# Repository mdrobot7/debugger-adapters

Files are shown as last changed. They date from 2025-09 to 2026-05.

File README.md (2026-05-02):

# debugger-adapters
Aliexpress STLINKv2 debugger to standard connector adapters

## Hardware
All part links are built into the KiCad parts, just generate the BOM from within KiCad and order. Miscellaneous parts are below.

- [Aliexpress STLINKv2](https://www.aliexpress.us/item/3256803389306042.html)
- [Cortex-debug Ribbon Cable](https://www.digikey.com/en/products/detail/cnc-tech/300-30-10-GR-0100F/5864892)
- [Pre-assembled Cortex-debug Cable](https://www.aliexpress.us/item/3256805917162371.html)

## Assembly
The ribbon cable IDC connectors for the Cortex-Debug adapter are quite difficult to get exactly right. If the wire goes in at slightly the wrong angle, the conductors will bridge or connect to the wrong pins. After each connector is put on, check each pin with a multimeter to make sure it's not bridged to anything it shouldn't be.

## Creating a Black Magic Probe
Black Magic Probe and Black Magic Debug are open-source SWD/JTAG debug projects for ARM Cortex microcontrollers. It gives you a bare GDB server and is platform-independent, so it will work on ARM Cortex microcontrollers regardless of brand or series.

To create a Black Magic Probe you need an existing debugger -- another Black Magic Probe, STLink (for ST-based debuggers), Atmel ICE (for Atmel chips), etc.

#### Resources
- [Black Magic Debug Website](https://black-magic.org/index.html)
- [Black Magic Debug Codeberg](https://codeberg.org/blackmagic-debug/blackmagic)
- [dfu-util Homepage](https://dfu-util.sourceforge.net/)
- [Zadig (Windows USB driver reinstaller)](https://zadig.akeo.ie/)

### Supported Hardware
- [Knockoff STLink v2 (Geehy MCU) - Aliexpress](https://www.aliexpress.us/item/3256803389306042.html)
- [Knockoff STLink v2 (STM32F101 MCU) - Aliexpress](https://www.aliexpress.us/item/3256803289344865.html)
- [STM32 "Blue Pill" (STM32F103C8T6) - Ebay](https://www.ebay.com/itm/292145343898)

### Wiring
Keep the SWD wires (between the BMP and the microcontroller) relatively short. SWD doesn't have a length spec, but under 30cm is a good rule of thumb. Slower baud rates will allow for longer lengths. It's recommended to extend the USB side instead of the SWD side.

### Reprogramming the BMP
The Black Magic Probe project switched to Meson in current releases, which makes installation a little harder on Windows. On Windows, your best move is load up a Linux VM using VirtualBox or something similar. You can try to get MSYS2 to work, but no guarantees. Builds and uploads on Windows may need [Zadig](https://zadig.akeo.ie/) to manually assign Windows drivers to your BMP, you want to assign it to **WinUSB**.

Instructions for Linux/Mac:

1. Install dependencies
   - Linux: `sudo apt install meson ninja gcc-arm-none-eabi gdb-multiarch binutils-arm-none-eabi dfu-util libhidapi-dev libftdi1-dev libusb-1.0-0-dev`
   - OSX: `brew install meson ninja arm-none-eabi-gcc arm-none-eabi-binutils arm-none-eabi-gdb dfu-util hidapi libftdi libusb`
3. `git clone https://codeberg.org/blackmagic-debug/blackmagic`
4. `cd` into the directory you cloned into
5. Set up the build: `meson setup build --reconfigure --cross-file cross-file/stlink.ini -Dtargets=cortexar,cortexm,sam,stm,nxp,ti -Dbmd_bootloader=true`
   - Which targets you choose are up to you and your use case. The ones shown above are a general recommendation. See [supported targets](https://black-magic.org/supported-targets.html) for others.
6. Build the binary and bootloader: `meson compile -C build; meson compile -C boot-bin`
7. Pull the metal shell off of your BMP-to-be by pulling it towards the USB port. Attach jumper wires to an existing BMP, and wire GND, VCC, SWDIO, and SWCLK to the pins/exposed pads on your BMP-to-be. You can wire it properly, or hold wires onto the pads until the next command is done.
8. Flash the bootloader
   - With an existing BMP: `arm-none-eabi-gdb -ex "tar ext [debugger device ID]" -ex "mon s" -ex "att 1" -ex "mon option erase" -ex "load" -batch build/blackmagic_stlink_bootloader.elf`
     - Find the debugger device ID in /dev. Use /dev/whatever for the following commands.
     - This worked on some targets (Geehy micros), but not all. I've received knockoff STLinks from AliExpress that have flash protections set up such that it doesn't flash. If so, grab a stock STLink and try the steps below.
   - With an existing STLink (credit to [this guide](https://microcontrollerelectronics.com/how-to-convert-an-stm32f103c8t6-into-a-black-magic-probe/)):
     - `sudo apt install openocd stlink-tools`
     - `sudo vim /usr/share/openocd/scripts/target/stm32f1x.cfg` and add `set CPUTAPID 0` below line 35. This disables CPU ID checking (we're flashing a counterfeit).
     - Plug in your existing STLinkv2 and connect it to your BMP-to-be.
     - `openocd -f interface/stlink-v2.cfg -f target/stm32f1x.cfg -c "init" -c "halt" -c "stm32f1x unlock 0" -c "shutdown" && st-flash erase && st-flash --flash=0x20000 --reset write build/blackmagic_stlink_bootloader.bin 0x8000000`
9. Plug your new BMP into your PC via USB, **unplug your existing debugger**.
10. Check that your new BMP shows up: `sudo dfu-util -l`. It should say "found DFU" with some device information.
11. Flash the BMP firmware: `sudo dfu-util -s 0x08002000:leave:force -D build/blackmagic_stlink_firmware.bin`

### Upgrading Your BMP
All you need to do is `git pull` the updated BMP firmware (or make any changes you need to), and rebuild. Plug it in via USB and rerun step 11 above. The bootloader handles reflashing the firmware over USB.

Black Magic Probe releases official binaries as well, so you can also download the `blackmagic-native` BIN file from the [Releases](https://codeberg.org/blackmagic-debug/blackmagic/releases) page and flash it over DFU. It covers a very similar set of debug targets and fits in the 128KB flash of our counterfeit STLinks.

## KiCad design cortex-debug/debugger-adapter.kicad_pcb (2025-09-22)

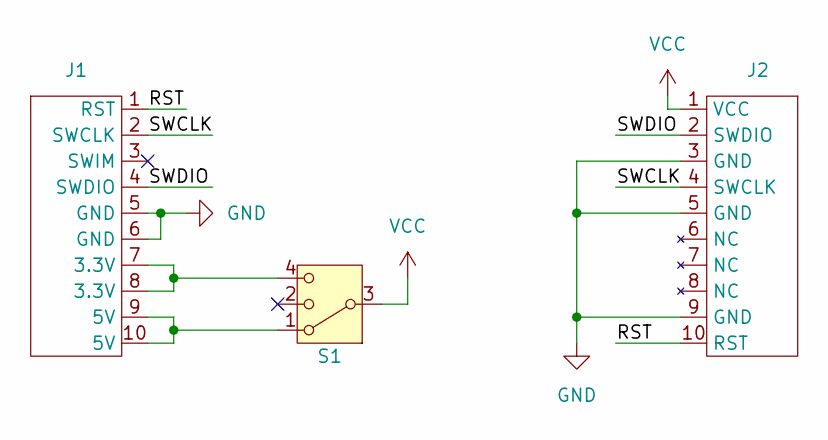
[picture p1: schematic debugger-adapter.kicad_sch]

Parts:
J1: STLINK_Header; Manufacturer Part Number SFH11-PBPC-D05-ST-BK; Digikey Part Number S9194-ND
J2: 0.05in_Ribbon_Header; Manufacturer Part Number 3240-10-00; Digikey Part Number 1175-1664-ND
S1: Slide_SP3T; Manufacturer Part Number CL-SB-13A-01T; Digikey Part Number 563-1326-1-ND

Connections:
/RST: J1.1 (RST), J2.10 (RST)
/SWCLK: J1.2 (SWCLK), J2.4 (SWCLK)
/SWDIO: J1.4 (SWDIO), J2.2 (SWDIO)
GND: J1.5 (GND), J1.6 (GND), J2.3 (GND), J2.5 (GND), J2.9 (GND)
unnamed: J1.7 (3.3V), J1.8 (3.3V), S1.4
unnamed: J1.9 (5V), J1.10 (5V), S1.1
VCC: J2.1 (VCC), S1.3

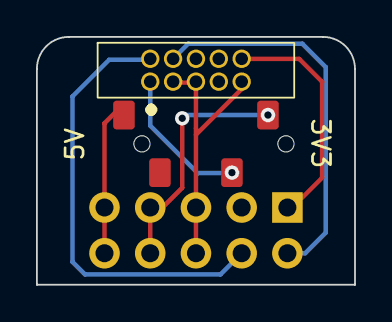
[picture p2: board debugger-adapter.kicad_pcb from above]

Board: 2 copper layers, 17.7 x 13.8 mm, 3 parts (1 on the bottom side), 7 nets.

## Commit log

2024-02-16 Created cortex debug/swd debugger adapter
    I already made this in altium, this is the kicad version of it. Made all of the parts in their own common library so that making different adapters is easy in the future for stuff like JTAG, ST, AVR,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
    [debugger-adapter.kicad_pcb, debugger-adapter.kicad_sch]
2024-02-19 Added part links
    [debugger-adapter.kicad_sch]
2024-11-24 Add aliexpress pre-assembled cable to readme, export project files
    [debugger-adapter.kicad_pcb, debugger-adapter.kicad_sch]
2025-02-19 Update stlink connector footprint to a better part
    - No more jankily soldering in an IDC connector, found an actual connector that works
    [debugger-adapter.kicad_pcb, debugger-adapter.kicad_sch]
2025-09-22 Replace solder jumpers with selector switch
    I got annoyed that my debugger was set for the wrong
    voltage or set to provide power when I didn't want it to, so
    small revision to add a selector switch. Makes the board a little bigger
    but whatever.
    [debugger-adapter.kicad_pcb, debugger-adapter.kicad_sch]
2025-09-22 Fix symbol and footprint library paths
2026-05-02 Update README with new build and program instructions
    Ran into a bunch of issues building for and programming this latest
    round of knockoff BMPs. AliExpress sent me a new type of counterfeit
    "STM32F103" that had some sort of flash or boot protections enabled on
    it that didn't disable easily, it seems like the only thing that can do
    it is OpenOCD. Conveniently, I had a bunch of STLinks to work with :)
